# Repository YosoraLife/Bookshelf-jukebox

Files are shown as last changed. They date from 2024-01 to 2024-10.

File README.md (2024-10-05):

# Bookshelf jukebox powered by Plexamp

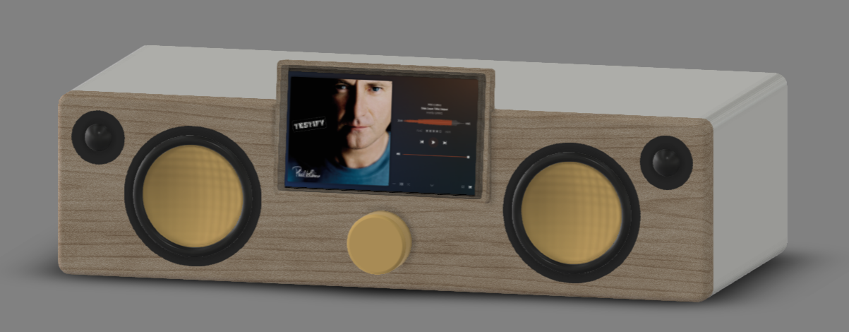
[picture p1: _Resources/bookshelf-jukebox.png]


Read more about this project on: [https://yosora.life/projects/diy-projects/a-bookshelf-jukebox/](https://yosora.life/projects/diy-projects/a-bookshelf-jukebox/)

This jukebox is based on the DIY speakers called "[Overnight Sensations](https://sites.google.com/site/undefinition/bookshelf-speakers/diy-overnightsensations)" by Paul Carmody. Those speakers are powered by a Raspbarry Pi with a high quality DAC and Amplifier. The jukebox itself has both physical controls as well as a touchscreen to interface with Plexamp. Futhermore I included a NFC reader (still a work in progress). This way I can scan a CD case with NFC sticker to play that CD on Plexamp, or setup NFC cards for different playlists based on my mood. 

#### Costs
The total costs for this build came around €475. See the [Bill of Materials](/BOM.md) for a complete specification. 

#### Building plans
The building plans for the jukebox itself can be found [here](/Building%20plans/Plexamp%20jukebox%20buildplan.pdf), and building plans for the speakers crossovers can be found [here](/Building%20plans/Speaker%20cross-over%20buildplan.pdf).

#### Installation instructions
And the installation instructions can be found [here](/INSTALL.md).

#### Specifications speakers
Power handling: 25 watts RMS/50 watts max<br>
Impedance: 8 ohms<br>
Frequency response: 45-20,000 Hz (-3 dB)<br>
Sensitivity: 83 dB 1W/1m

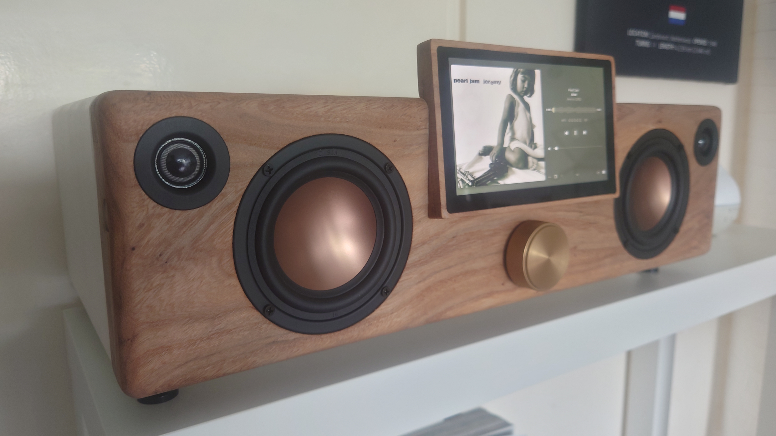
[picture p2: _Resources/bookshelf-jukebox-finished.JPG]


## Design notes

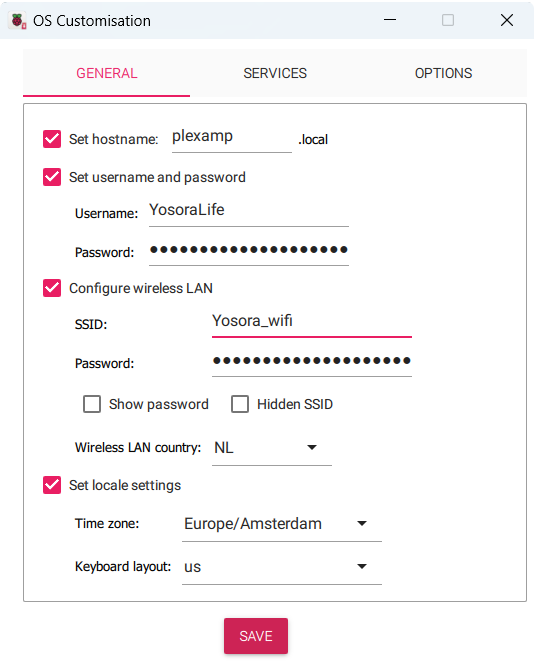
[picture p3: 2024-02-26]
_Resources/RPI_settings.png

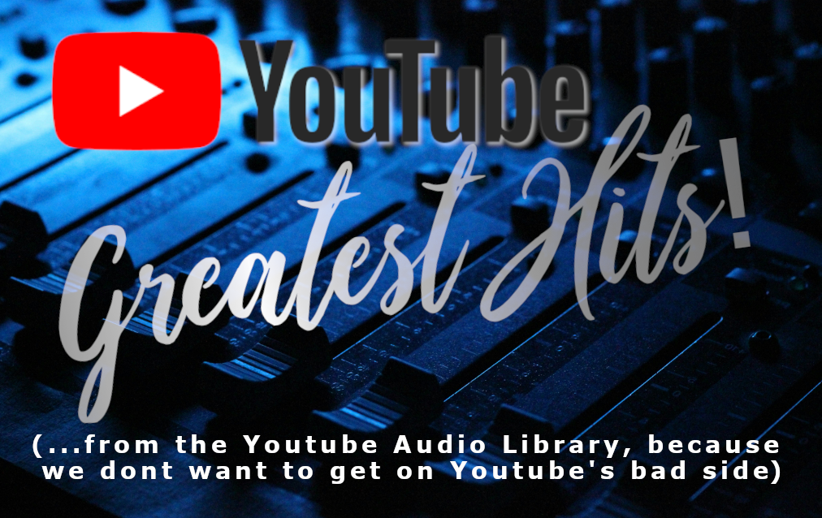
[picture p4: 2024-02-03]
_Resources/Extras/NFC card/Youtube-Greatest-Hits.png

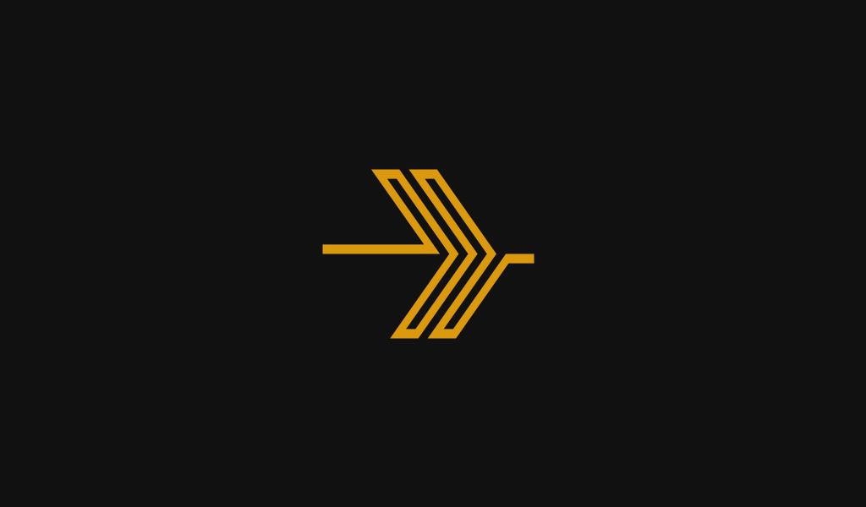
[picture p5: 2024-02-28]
plexamp-splash.png

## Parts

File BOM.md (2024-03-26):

# Bill of materials

### Raspberry Pi
| Amount  | Item  | Total price |
| --- | --- | --- |
| 1 | [Raspberry Pi 3](https://www.raspberrypi.com/products/raspberry-pi-3-model-b-plus/)  | €44,95  |
| 1 | [IQaudIO Pi-DigiAMP+](https://www.raspberrypi.com/products/digiamp-plus/) <br>Also known as Raspberry Pi DigiAMP+  | €34,95  |
| 1 | [Waveshare 7 inch QLED Touch Display](https://aliexpress.com/item/1005004634702269.html) <br>with development board | €77,50 |
| 1 | [NFC PN532 kit](https://aliexpress.com/item/1005005973913526.html) | €4,65 |
| 1 | Power supply 24V @4A *(see notes at the bottom)| €34,95 |
| | **Subtotal** | **€197,00** |

### Speaker components
The speakers are based on the DIY speaker design "[Overnight Sensations](https://sites.google.com/site/undefinition/bookshelf-speakers/diy-overnightsensations)" 
| Amount  | Item  | Total price |
| --- | --- | --- |
| 2	| [Dayton Audio DNR-10 10 Ohm 10W](https://www.soundimports.eu/en/dayton-audio-dnr-10.html) | €2,98 |
| 2	| [Dayton Audio DNR-6.0 6 Ohm 10W](https://www.soundimports.eu/en/dayton-audio-dnr-10.html) | €2,98 |
| 2	| [Dayton Audio DMPC-0.22 0.22uF 250V](https://www.soundimports.eu/en/dayton-audio-dmpc-022.html) | €2,50 |
| 2	| [Dayton Audio DMPC-1.5 1.5uF 250V](https://www.soundimports.eu/en/dayton-audio-dmpc-1-5.html) | €2,90 |
| 2	| [Dayton Audio DMPC-2.2 2.2uF 250V](https://www.soundimports.eu/en/dayton-audio-dmpc-22.html) | €3,70 |
| 2	| [Dayton Audio DMPC-6.8 6.8uF 250V](https://www.soundimports.eu/en/dayton-audio-dmpc-6-8.html) | €6,50 |
| 2	| [Jantzen 1204 0.35mH 20 AWG](https://www.soundimports.eu/en/jantzen-audio-000-1204.html) | €7,70 |
| 2	| [Jantzen 1078 1.1mH 18 AWG](https://www.soundimports.eu/en/jantzen-audio-000-1078.html) | €18,90 |
| 2	| [Dayton Audio ND20FA-6 Tweeter](https://www.soundimports.eu/en/dayton-audio-nd20fa-6.html) | €29,90 |
| 2	| [HiVi B4N Aluminum Midbass](https://www.soundimports.eu/en/hivi-b4n.html) | €44,90 |
| 2 | [Perforated PCB 95*70mm](https://www.soundimports.eu/nl/320-470.html) <br>Alternative: [Crossover PCB for the Overnight Sensations](https://www.ebay.com/itm/283420027089) | €5,90 <br> $20,00 (€18,70)|
| 1 | [Speaker damping](https://www.soundimports.eu/nl/monacor-mdm-2.html) | €10,45 |
| 1 | 1 meter of 32mm PVC pipe for water drainage | €2,79 |
| 2 | 90 degrees bend  for 32mm PVC pipe | €1,90 |
| | **Subtotal** | **€144** |

### Miscellaneous
| Amount  | Item  | Total price |
| --- | --- | --- |
| 1 | Elm wood plank 20x160x1,8cm | €21,45 |
| 1 | MDF 61c122x1,8cm | €16,49 |
| 2 | 2m loudspeaker cable 1,5mm2 | €6,00 |
| 2 | [TTP223 Touch-Knop Module](https://aliexpress.com/item/1005005981286756.html) <br>minimum order of 10, only 2 needed | €0,94 (10st) |
| 1 | [Rotary Encoder](https://aliexpress.com/item/33039321968.html) | €1,94 |
| 1 | [Rimini knob - matt brass 50mm](https://allegreepjes.nl/rimini-knop-mat-messing-50-mm.html) | €19,21 |
| 1 | [22mm metal toggle switch](https://aliexpress.com/item/1005005918066040.html) | €4,10 |
| 1 | [Speaker stands](https://aliexpress.com/item/4000427279953.html) | €8,59 |
| 1 | [Self-adhesive speakerwire foam](https://aliexpress.com/item/1005006204882391.html) | €2,23 |
| 1 | [2x20pin Dupont connectors + terminals](https://aliexpress.com/item/32951306845.html) | €4,30 |
| 1 | [PCB terminal](https://aliexpress.com/item/1005003373535370.html) <br>minimum order of 10, only 1 needed | €1,45 |
| 1 | [Braided heat shrink cable sleeve](https://aliexpress.com/item/1005006219473493.html) <br>diameter 6mm, length 3m | €2,95 |
| 1 | [5.5x2.5mm panel mounted DC connector](https://aliexpress.com/item/4000694128319.html) | €0,75 |
| 1 | [CAT6 ethernet panel mounted connector](https://aliexpress.com/item/1005005363341111.html) | €2,73 |
| 1 | [Rubio Monocoat Oil Plus 2C Pure 100+30ml](https://www.rubiomonocoat.nl/oil-plus-2c) | €30,45 |
| 1 | Matt white paint | €8,95 |
| | **Subtotal** | **€132,53** |

### Plexamp jukebox
**Total cost: €473,53**

Notes:

*To be clear, use all this information at your own risk. I'm not an expert at in this matter at all, and I also rely on information I found online (see resources). So I highly recommend you do your own research in this matter.*

*The digiamp+ can take any power supply ranging from 12-24V DC, with the recommended power supply being 19V, 3.4A (65 watt) DC. That being said, the input voltage does effect the output power per channel. Since the speakers are rated at 25 watts RMS and an impedance of 8 ohms. A recommended amplifier would need 37,5 watts per channel output. At 19V, 8 ohms the IQaudio DigiAmp+ povides an output of 21.3 watts. While at 24V, 8 ohms the IQaudio DigiAmp+ povides an output of 36 watts. And since there is a higher output it also requers a higher input, so a 24V, 4A (96 watt) DC power supply.

But even with a supply voltage of 24V the IQaudio DigiAmp+ is slightly underpowered. So if you would want to use the speakers at maximum volume this could cause problems. But (at least for me) the point of a jukebox is to provide some background music and its not meant to be used at the maximum volume. So then what would the maximum volume be? Well the speakers have a sensitivity of 83 dB 1W/1m. Wich means that at a listing distince of 1 meter a single speaker has a maximum output level of 96,3dB@21,3 watts and 98,6dB@36 watts. Or at a more reasonable lisiting distance of 4 meters this becomes 84,3dB@21,3 watts or 86,6dB@36 watts.

| Power supply voltage | Output power, 8 ohms | 1m listing distance  | 4m listing distance |
| --- | --- | --- | --- |
| 19V | (2x) 21,3 watts | 96,3dB | 84,3dB |
| 24V | (2x) 36 watts | 98,6dB | 86,6dB |

For reference, sounds above 85dB are considered harmfull, while normal level to listen to music would be more around 70dB.

Resources:<br>
[Choosing the right amplifier for your speakers](https://www.gear4music.com/blog/choosing-the-right-amplifier-for-your-speakers/)<br>
[TAS5756M Class-D Amplifier](https://www.ti.com/lit/ds/symlink/tas5756m.pdf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)<br>
[Understanding speaker sensitivity](https://geoffthegreygeek.com/understanding-speaker-sensitivity/)

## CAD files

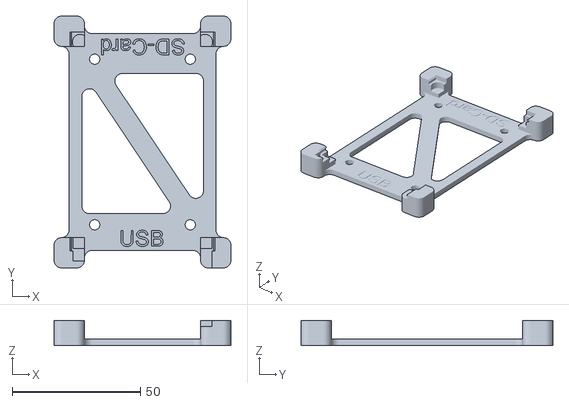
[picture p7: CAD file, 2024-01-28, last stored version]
3D print files/raspberrypi-plate.stl
69.0 x 98.2 x 9.75

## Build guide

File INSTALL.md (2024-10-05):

# Installation instructions bookshelf jukebox

[TOC]

## Prerequisites
### Plex
This installation asummes that you have an active Plex server. [Plex](https://www.plex.tv) is software to manage your personal media collection (Movies, TV series and Music). Plex consist of 2 parts, a central server (Plex Media Server) to manage and stream the media. And the client to play the media. This installation uses Plex dedicated music player called Plexamp for the playback of music. To be able to use the headless version of Plexamp you do need an paid PlexPass subscription.

### NFC reader
The NFC reader was a bit tricky to setup, this code is tested, and meant to be used with:

- A S50 Mifare Classic 1K NFC compatible [card](https://aliexpress.com/item/1005006282512971.html), [sticker](https://aliexpress.com/item/1005005823042872.html) or [FOB](https://aliexpress.com/item/1005006029241048.html) :
- a [Elechouse PN532 V3 NFC/RFID card reader](https://aliexpress.com/item/1005005973913526.html)

### Jukebox
Take a look at the [Bill of Materials](/BOM.md) for a complete list of materials. Building plans for the jukebox itself can be found [here](/Building%20plans/Plexamp%20jukebox%20buildplan.pdf), and building plans for the speakers crossovers can be found [here](/Building%20plans/Speaker%20cross-over%20buildplan.pdf).

## Wiring
The IQaudio DigiAMP+ is connected directly to the Raspberry Pi GPIO header. The power is provided to the IQaudio DigiAMP+ (12-24V DC) that in its turn also provides power to the Raspberry Pi itself. The IQaudio DigiAMP+ also provide GPIO passthrough.

The NFC reader, rotary encoder and 2 touch buttons need to be wired according to following GPIO pins:

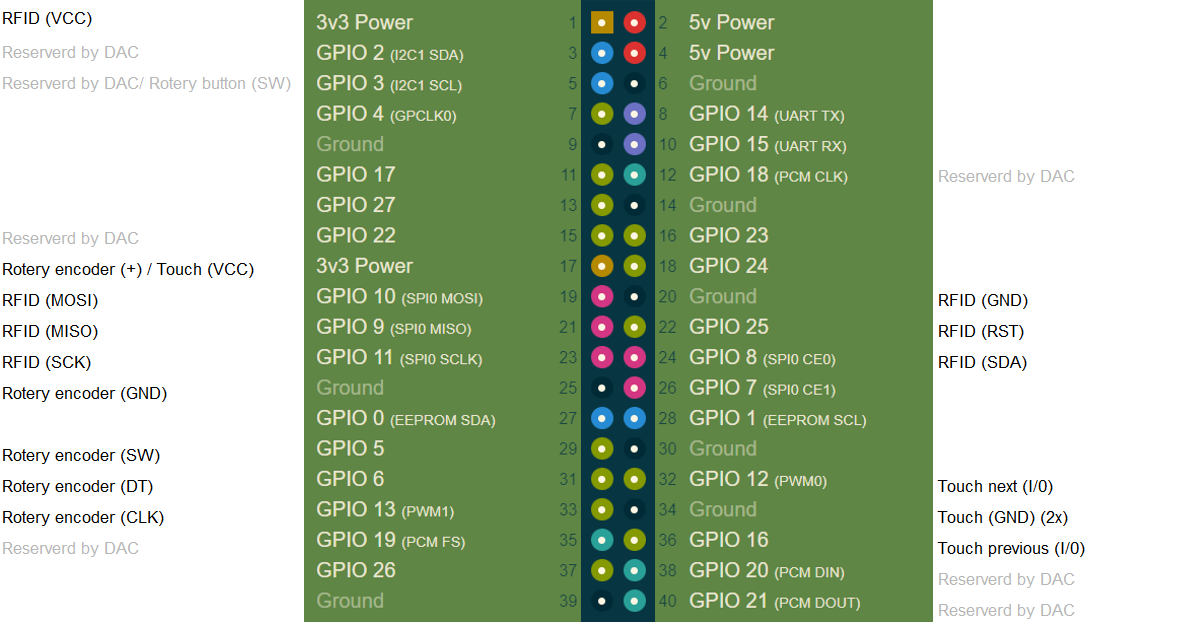
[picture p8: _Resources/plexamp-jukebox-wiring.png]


For reference pin 1 is on the SD card side and pin 40 is on the USB side.

Note: The rotery button (sw) is connected BOTH to pin 5 and pin 29. When the Raspberry Pi is powered off it can be turned on by connecting pin 5 to ground. But when the Raspberry Pi is powered on pin 5 is exclusively used by the DAC and can therefore pin 29 is used instead.

## Installation of the hardware
Download the [DietPi Bookworm](https://dietpi.com/#downloadinfo) image for Raspberry Pi 2/3/4/Zero 2 (ARMv8). unzip it with a tool like [7Zip](https://www.7-zip.org). I always prefer to use [rufus](https://rufus.ie/) to flash the dietpi.img to a SD card. Wait for the flashing process to be finished.

Dietpi has some great way to automate the setup process. Follow the follow steps in order to make use of that:

### Setup wifi
The following steps are only needed if you want to make use of WiFi, open the SD card folder, and update next two files using a text editor:

In the file dietpi-wifi.txt:

- set `aWIFI_SSID[0]` to the name of your WiFi network (keep the qoutes)
- set `aWIFI_KEY[0]` to the password of your WiFi network (keep the qoutes)

Save and close the file

**Enable wifi:**
In the file named dietpi.txt:

- find `AUTO_SETUP_NET_WIFI_ENABLED` and set to value `1`
- find `AUTO_SETUP_NET_WIFI_COUNTRY_CODE` and set it too the correct countrycode

### Setup locale
(Still) In the file dietpi.txt:

- find `AUTO_SETUP_LOCALE=c.UTF-8`, change the c.UTF-8 for your own localization. In my case this would be `nl_NL.UTF-8` or for English: `en_GB.UTF-8`. Im not sure if this is 100% necessary but the first time running without this caused the keyboard setup to fail.
- find `AUTO_SETUP_KEYBOARD_LAYOUT`, set the keyboard layout. You only need the keyboard to login to the Plexamp userinterface
- find `AUTO_SETUP_TIMEZONE` and set your correct timezone

### Setup dietpi:
(Still) In the file dietpi.txt:

- find `AUTO_SETUP_NET_HOSTNAME` and set it to: `Jukebox`
- find `AUTO_SETUP_CUSTOM_SCRIPT_EXEC` and set it to: `https://gitlab.com/YosoraLife/bookshelf-jukebox/-/raw/main/jukebox-install.sh` (no qoutes needed)
- find `AUTO_SETUP_BROWSER_INDEX` and set it to `-2`
- find `AUTO_SETUP_AUTOSTART_TARGET_INDEX` and set it to `11`
- find `AUTO_SETUP_AUTOSTART_LOGIN_USER` and set it to `root`
- find `AUTO_SETUP_AUTOMATED` and set it to `1`
- find `AUTO_SETUP_INSTALL_SOFTWARE_ID` and add to the line underneath:

```bash
AUTO_SETUP_INSTALL_SOFTWARE_ID=5 # Install ALSA
AUTO_SETUP_INSTALL_SOFTWARE_ID=17 # Install Git
AUTO_SETUP_INSTALL_SOFTWARE_ID=69 # Install RPi.GPIO
AUTO_SETUP_INSTALL_SOFTWARE_ID=72 # Install I2C
AUTO_SETUP_INSTALL_SOFTWARE_ID=113 # Install Chromium
AUTO_SETUP_INSTALL_SOFTWARE_ID=130 # Install Python 3 pip
```

- find `SURVEY_OPTED_IN` and set it to what your comfortable with
- find `SOFTWARE_CHROMIUM_RES_X` and set it to your screens width, in my case `1024`
- find `SOFTWARE_CHROMIUM_RES_Y` and set it to your screens height, in my case `600`
- find `SOFTWARE_CHROMIUM_AUTOSTART_URL` and set it to: `http://127.0.0.1:32500/`

### Recommandations:

- find `AUTO_SETUP_GLOBAL_PASSWORD` and change the root password

Save and close the file

### Setup screen
In the file named config.txt add to the bottom:

```bash
hdmi_group=2
hdmi_mode=87
hdmi_cvt 1024 600 60 6 0 0 0
hdmi_drive=1
# Disable HDMI audio
dtoverlay=vc4-kms-v3d,noaudio
# Enable DAC
dtoverlay=iqaudio-dacplus,unmute_amp
```

Save and close the file. And now its time to put the sd card in the Raspberry Pi and boot up for the first time. The installation of all the required software starts automaticly. The Raspberry Pi does need an active internet connection. So make sure you either have set up a wired or a wireless connection.

Dietpi automatically run through all installation steps. Near the end you will be prompted to enter your Plex claim code followed by the prompt to name your Plexamp player. Make sure you have a keyboard connected to the Raspberry Pi for this. When finished the Raspberry Pi will reboot into the Plexamp interface. Even though you claimed the Plexamp player already you will still need to do a (onetime) login into the (web)interface with your Plex credentials. For this you also need to have a keyboard connected to your Raspberry Pi. After this you don't need an keyboard anymore since you can use SSH to access the jukebox.

## SSH into the jukebox
You can use SSH to access the jukebox from another computer. Use a tool like [Advanced IP scanner](https://www.advanced-ip-scanner.com/) to find the IP address of the Jukebox. Next use [PuTTY](https://www.putty.org) to connect to the jukebox. The username is root, and the default password is "dietpi", although you should have changed that in the previous step.

### Enable autoplay on boot
By default Plexamp doesnt start playing until music is choosen. You can enable the script to autoplay the (general) Library radio.

In a webbrowser go to the following page on you **Plex Media Server** and find the *machineIdentifier*

```bash
http://[IP  address]:32400/identity/
```

Edit the Plexamp controls:

```bash
cd  ~/bookshelf-jukebox
sudo nano settings.py
```
Find `PLEX_ID` and set the machineIdentifier.

Here you can also change the short and long press duration, the volume adjustment steps, starting volume at boot and screen timeout at idle (no playing).

### Changing sound levels

Now these speakers can go LOUD! If you ask me, way too loud. I like to use this bookshelf speakers more as background music, and only occasionally turning op the volume. But even when I do turn up the volume I could never push them above 50% volume on Plexamp, while only being more around 5% volume at background music levels.

This would make the volume knob pretty useless of course. Luckily there is a way to manage this. You can adjust the maximum volume levels for the soundcard. By changing the maximum levels for the soundcard you can use the entire volume range on Plexamp.

Open AlsaMixer:
```bash
alsamixer
```

Choose the sound card by hitting `F6` and selecting IQaudIODAC. You will now see different sound levels meters. Use the left and right arrow keys to select the "Digital" sound level meter, and use the up and down arrow keys to change the sound levels. This can be done while playing music. I set mine to 67%.

When the desired level is set hit the ESC key to exit alsamixer.

## Controlling the Jukebox

### Turning off/on
If you build your jukebox just like mine you will have a power toggle at the back, and at the front a volume control knob and a previous/next touch button. DO NOT use the power toggle to shutdown the Raspberry Pi, this can cause a corrupt SD card! 

The correct way of shutting down is to long press the volume knob until the system is in idle state. Only then it's safe to turn off the power toggle. When the power toggle is turned on it will automatically boot the system. Alternatively if the system is still in idle state it can be turned back on by pressing the volume knob.

### Physical controls
You can use the touchscreen, volume knob and previous/next touch buttons. The volume knob also doubles as play/pause (short press) or off/on (long press).

### Control by phone
You can control the jukebox with the Plexamp app for both iPhone and Android. Use the cast function in the app and select the jukebox. Your phone will now work as a remote for the jukebox.

### Control by web browser
Similarly you can control the jukebox by going to `http://[IP  address]:32500/`

## Updating plexamp
Check the [plexamp download](https://www.plex.tv/media-server-downloads/?cat=headless&plat=raspberry-pi#plex-plexamp) page to see the required NodeJS (Node) version

Check if the right version is installed:

```bash
node  -v
```

If needed update NodeJS

```bash
NODE_MAJOR=20
echo  deb [signed-by=/etc/apt/keyrings/nodesource.gpg] https://deb.nodesource.com/node_$NODE_MAJOR.x nodistro main | sudo  tee  /etc/apt/sources.list.d/nodesource.list
sudo  apt-get  update && sudo  apt-get  install  -y  nodejs
```

replace `20` with the required NodeJS version

Check for update (one time):

```bash
sh  /root/bookshelf-jukebox/plexamp-upgrade.sh
```

You can setup an automatic weekly update run: 

```bash
sudo (crontab -l; echo  "@weekly /usr/bin/sh /root/bookshelf-jukebox/plexamp-upgrade.sh &")|awk  '!x[$0]++'|crontab  -
```

 Be aware: this will only run the plexamp update script and it will not update NodeJS. 
At times a newer version of Plexamp also requires a newer version of NodeJS (Node). The required version of NodeJS (node) can be found on the download page: https://www.plex.tv/media-server-downloads/?cat=headless&plat=raspberry-pi#plex-plexamp

To check the installed version of NodeJS connect to the Raspberry Pi through SSH an run the command: node -v

If needed update NodeJS

```bash
NODE_MAJOR=20
echo  deb [signed-by=/etc/apt/keyrings/nodesource.gpg] https://deb.nodesource.com/node_$NODE_MAJOR.x nodistro main | sudo  tee  /etc/apt/sources.list.d/nodesource.list
sudo  apt-get  update && sudo  apt-get  install  -y  nodejs
```

replace `20` with the required NodeJS version

And finally reboot:
```bash
sudo reboot now
```

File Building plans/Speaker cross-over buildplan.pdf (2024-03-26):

Full credits to user “Soundslike” on the parts-express.com forum for making crossover build plan. For the original post: https://techtalk.parts-express.com/forum/speaker-project-gallery/42859-overnight-sensation-build-two-sets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 (https://techtalk.parts-express.com/forum/speaker-project-gallery/42859-overnight-sensation-build-two-sets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)

## Materials needed

For the Materials needed look at the Bill of materials > Speaker components (https://gitlab.com/YosoraLife/bookshelf-jukebox/-/blob/main/BOM.md?ref_type=heads#speaker-components)

## Wiring diagram

This wiring diagram is in mirrored view. So as if you where looking through the board from the bottom side. The red and blue lines are connection lines and the dots is where the connection lines meet. If 2 connection lines cross without a dot there shouldn’t be an electrical connection made.

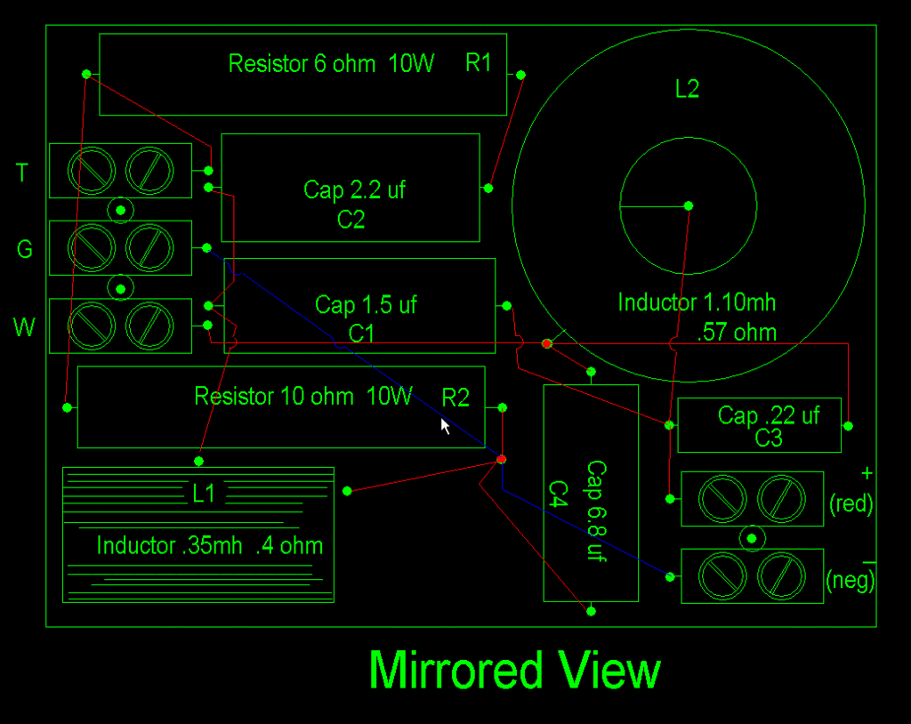
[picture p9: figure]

## Results

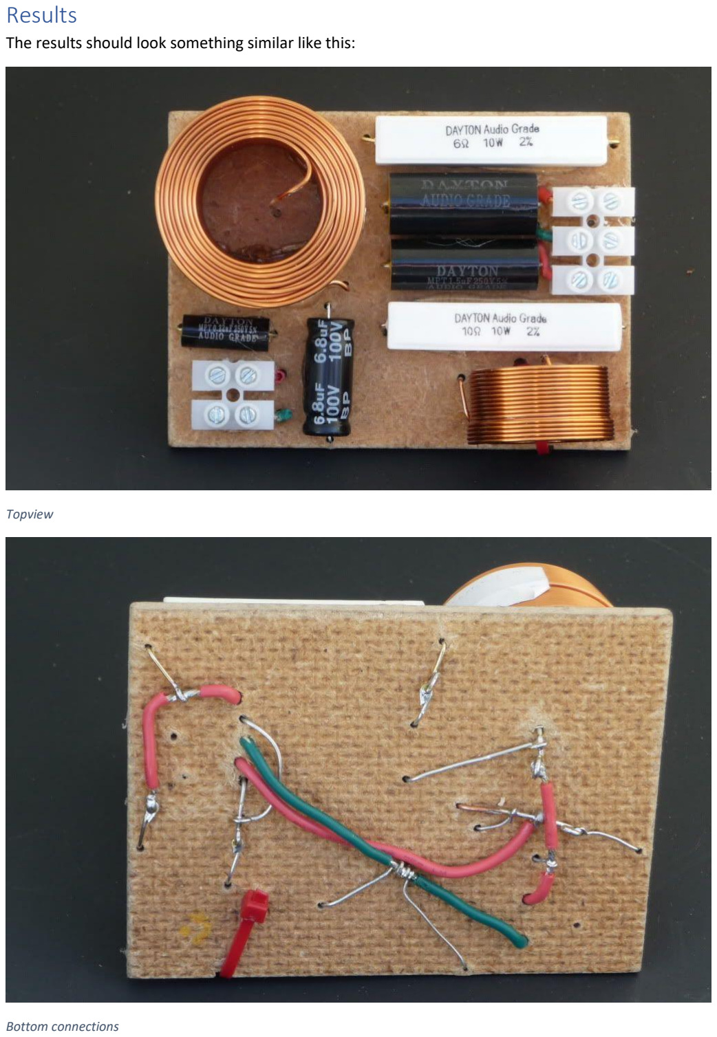
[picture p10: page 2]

The results should look something similar like this:

Topview

Bottom connections

## Connecting the speakers

On the input side the terminal on the outside of the board is the negative (-) terminal, while the other one is the positive (+) terminal as indicated on the picture below.

On the output side the middle terminal is the ground (G) terminal. To this terminal you need the negative (-) side of the woofer and the positive (+) side of the tweeter.
The positive tweeter (T) terminal need to connect to the negative (-) side of the tweeter.
And the positive woofer (W) terminal needs to connect to the positive (+) side of the woofer.

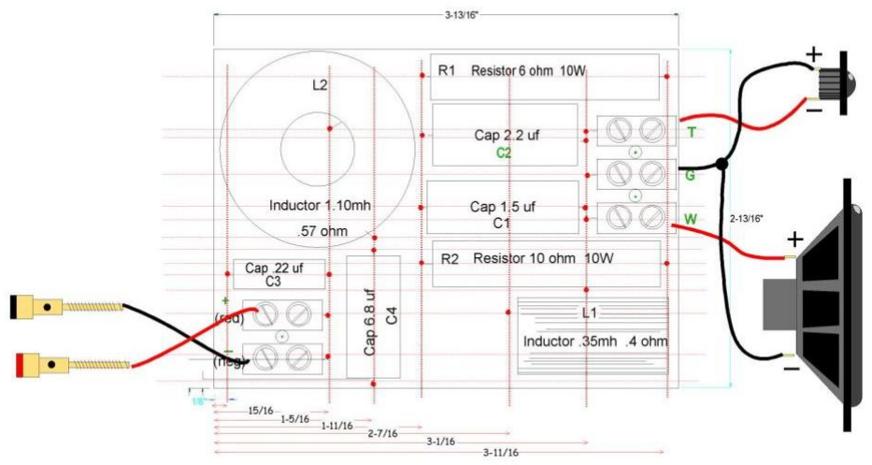
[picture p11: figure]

Tip: Test if everything works before you mount it in the speaker cabinate.

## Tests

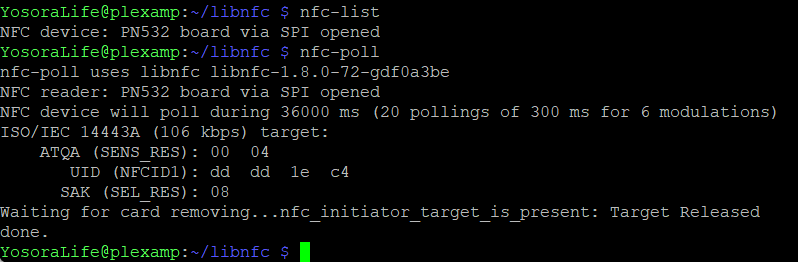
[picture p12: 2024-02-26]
_Resources/nfc-test.png

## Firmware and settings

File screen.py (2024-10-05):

#! /usr/bin/env python3
# Bookshelf jukebox screen control

import time
import settings
from functions import getState, setScreen

##########################################################################################################
####### DONT CHANGE THE SETTINGS INBETWEEN THESE LINES. INSTEAD CHANGE THE SETTINGS IN SETTINGS.PY #######

# Screen backlight control
SCREEN_TIMEOUT = settings.SCREEN_TIMEOUT                            # Turn screen backlight off after * minutes

####### DONT CHANGE THE SETTINGS INBETWEEN THESE LINES. INSTEAD CHANGE THE SETTINGS IN SETTINGS.PY #######
##########################################################################################################

###################################################
### Initial state setup ###########################
###################################################
SCREEN_TIMEOUT_START = time.time()                                  # Start tracking of the time
PB_PREV_STATE = 'paused'                                            # Assume the initial state of the player is paused
setScreen('on')                                                     # Start with the screen on

###################################################
### Paused state handeling ########################
###################################################
def handle_paused_state():
    global SCREEN_TIMEOUT_START
    screen_timeout_duration = time.time() - SCREEN_TIMEOUT_START    # Calculate the time duration since last pause
    if screen_timeout_duration > (SCREEN_TIMEOUT * 60):             # Check if timeout time is already exceeded
        setScreen('off')                                            # Turn off screen

###################################################
### Playing state handeling #######################
###################################################
def handle_playing_state():
    setScreen('on')                                                 # Turn on screen, playback has started

while True:
    current_state = getState('state')                               # Get the current state

    if current_state == 'playing':                                  # State is playing
        if PB_PREV_STATE != 'playing':                              # Previous state was not playing
            PB_PREV_STATE = 'playing'                               # Set new previous state variable
            handle_playing_state()                                  # Turn on screen, playback has started

    else:                                                           # If state is paused or stopped
        if PB_PREV_STATE == 'playing':                              # Previous state was playing
            PB_PREV_STATE = 'paused'                                # Set new previous state variable
            SCREEN_TIMEOUT_START = time.time()                      # Reset tracking of the time
        handle_paused_state()                                       # Check if the screen should turn off after timeout

    time.sleep(5)                                                   # Run loop once every 5 seconds to reduce CPU usage

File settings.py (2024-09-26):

#! /usr/bin/env python3
# Bookshelf jukebox setings

# Times for button presses
SHORT_PRESS_TIME = 1.5                      # Time for shortpress in seconds
LONG_PRESS_TIME = 2.0                       # Time for longpress in seconds
DEBOUNCE_TIME = 100                          # Debounce time in mili seconds, default = 100. Increase when experience unwanted "extra" button presses 

# Volume steps
VOLUME_ADJUSTEMENT = 3                      # How much to add to the volume every step. Range: 0-100

# At boot there is no playlist yet. For autoplay library radio to work you need the machineIdentifier of your plexserver
PLEX_ID = ''                                # Find the machineIdentifier at http://[IP address]:32400/identity/
AUTOPLAY = 0                                # 0 = Autoplay on start (dont forget to fill in your PLEX_ID), 1 = No autoplay on start
START_VOLUME = 10                           # Set volume level at start Range: 1-100, 0 = disable

# Screen backlight control
SCREEN_TIMEOUT = 5                          # Turn screen backlight off after * minutes

# Pin numbers on Raspberry Pi
CLK_PIN = 13                                # GPIO7 connected to the rotary encoder's CLK pin
DT_PIN = 6                                  # GPIO8 connected to the rotary encoder's DT pin
SW_PIN = 5                                  # GPIO5 connected to the rotary encoder's SW pin
NEXT_PIN = 12                               # GPIO12 connected to the next song touch button pin
PREV_PIN = 16                               # GPIO16 connected to the previous song touch button pin
SCREEN_PIN = 23                             # GPIO23 connected to the screen backlight pin

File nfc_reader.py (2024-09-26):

#! /usr/bin/env python3

"""
    NFC Reader for Mifare Classic 1K cards using Elechouse PN532 V3 NFC/RFID card reader.
    Reads and converts the contents of the NFC card back to a URL and opens it.
"""

import curlify
import requests
import time

from pn532pi import pn532, Pn532
from pn532pi import Pn532Hsu
from pn532pi import Pn532Spi

SPI = True
HSU = False

# Configure NFC reader connection mode (SPI or HSU)
if SPI:
    PN532_SPI = Pn532Spi(Pn532Spi.SS0_GPIO8)
    nfc = Pn532(PN532_SPI)
elif HSU:
    PN532_HSU = Pn532Hsu(Pn532Hsu.RPI_MINI_UART)
    nfc = Pn532(PN532_HSU)


def setup():
    """Setup NFC module and wait until it is found."""
    module_found = False
    retries = 10  # Max retries to avoid indefinite looping
    while not module_found and retries > 0:
        nfc.begin()
        version_data = nfc.getFirmwareVersion()
        if version_data:
            module_found = True
        else:
            retries -= 1
            time.sleep(1)
    if module_found:
        nfc.SAMConfig()
    else:
        print("Error: NFC module not found. Exiting.")
        exit(1)


if __name__ == '__main__':
    setup()

    key_universal = bytearray([0xFF, 0xFF, 0xFF, 0xFF, 0xFF, 0xFF])

    while True:
        authenticated = False
        data_strings = ['http://']  # Collect strings in a list for better efficiency

        success, uid = nfc.readPassiveTargetID(pn532.PN532_MIFARE_ISO14443A_106KBPS)
        if success and len(uid) == 4:
            block_count = 0
            empty_block_count = 0

            # Try to read all 16 sectors (each sector has 4 blocks)
            for current_block in range(64):
                if block_count == 3:
                    block_count = 0  # Skip every 4th block (authentication block)
                    continue
                block_count += 1

                if nfc.mifareclassic_IsFirstBlock(current_block):
                    authenticated = False

                # Authenticate if needed
                retry_limit = 3
                while not authenticated and current_block > 3 and retry_limit > 0:
                    success = nfc.mifareclassic_AuthenticateBlock(uid, current_block, 1, key_universal)
                    if success:
                        authenticated = True
                    else:
                        retry_limit -= 1

                if authenticated:
                    empty_block = bytearray([0x00] * 16)
                    success, data = nfc.mifareclassic_ReadDataBlock(current_block)

                    if data == empty_block:
                        empty_block_count += 1
                        if empty_block_count > 3:
                            break  # Stop if more than 3 consecutive empty blocks are found
                    elif success:
                        empty_block_count = 0
                        if current_block == 4:
                            data = data[7:]  # Skip first 7 bytes (start of data)
                        data_strings.append(data.decode('utf8', 'ignore'))

        if data_strings:
            url = ''.join(data_strings).replace("listen.plex.tv", "localhost:32500")
            try:
                response = requests.get(url)
                print(curlify.to_curl(response.request))
            except requests.RequestException as e:
                print(f"Error opening URL: {e}")

        time.sleep(3)  # Sleep before the next read attempt

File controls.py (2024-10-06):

#! /usr/bin/env python3
# Bookshelf jukebox controls

import RPi.GPIO as GPIO
import time
import os
import settings
from functions import *

##########################################################################################################
####### DONT CHANGE THE SETTINGS INBETWEEN THESE LINES. INSTEAD CHANGE THE SETTINGS IN SETTINGS.PY #######

# Pin numbers on Raspberry Pi
CLK_PIN = settings.CLK_PIN                          # GPIO7 connected to the rotary encoder's CLK pin
DT_PIN = settings.DT_PIN                            # GPIO8 connected to the rotary encoder's DT pin
SW_PIN = settings.SW_PIN                            # GPIO5 connected to the rotary encoder's SW pin
NEXT_PIN = settings.NEXT_PIN                        # GPIO12 connected to the next song touch button pin
PREV_PIN = settings.PREV_PIN                        # GPIO16 connected to the previous song touch button pin

# Times for button presses
SHORT_PRESS_TIME = settings.SHORT_PRESS_TIME        # Time for shortpress in seconds
LONG_PRESS_TIME = settings.LONG_PRESS_TIME          # Time for longpress in seconds
DEBOUNCE_TIME = settings.DEBOUNCE_TIME              # Debounce time in milli seconds, default = 100. Increase when experience unwanted "extra" button presses 

# Volume steps
VOLUME_ADJUSTEMENT = settings.VOLUME_ADJUSTEMENT    # How much to add to the volume every step. Range: 0-100

# At boot there is no playlist yet. For autoplay library radio to work you need the machineIdentifier of your plexserver
PLEX_ID = settings.PLEX_ID                          # Find the machineIdentifier at http://[IP address]:32400/identity/
AUTOPLAY = settings.AUTOPLAY                        # 0 = Autoplay on start, 1 = No autoplay on start
START_VOLUME = settings.START_VOLUME                # Set volume level at start Range: 1-100, 0 = disable

####### DONT CHANGE THE SETTINGS INBETWEEN THESE LINES. INSTEAD CHANGE THE SETTINGS IN SETTINGS.PY #######
##########################################################################################################

# General variables
PRESS_TIME_START = 0
IS_PRESSED = False

# Configure GPIO pins
GPIO.setmode(GPIO.BCM)
GPIO.setup(CLK_PIN, GPIO.IN)
GPIO.setup(DT_PIN, GPIO.IN)
GPIO.setup(SW_PIN, GPIO.IN, pull_up_down=GPIO.PUD_UP)
GPIO.setup(NEXT_PIN, GPIO.IN, pull_up_down=GPIO.PUD_UP)
GPIO.setup(PREV_PIN, GPIO.IN, pull_up_down=GPIO.PUD_UP)

prev_clk_state = GPIO.input(CLK_PIN)                        # Read the initial state of the rotary encoder's CLK pin

###################################################
### Autoplay functionality ########################
###################################################
def autoplay():
    if AUTOPLAY == 0 and PLEX_ID != '':                     # Check if autoplay is enabled and a PLEX ID is present
        if START_VOLUME >= 1 and START_VOLUME <= 100:       # Check if there is a start volume set
            setState(START_VOLUME)                          # Set start volume
        setState('playMedia')                               # Start playback

###################################################
### Rotery encoder functionality ##################
###################################################
def rotary_encoder_callback(channel):
    #global prev_clk_state
    #if GPIO.input(CLK_PIN) != prev_clk_state:               # Detect state change of CLK pin
    # Check state of the DT pin
    if GPIO.input(DT_PIN) == GPIO.HIGH:                 # State DT pin is high? Then its turning counter-clockwise
        setState('volDown')                             # Turn volume down
    elif GPIO.input(DT_PIN) == GPIO.LOW:                # Else the state of DT pin is low. Then its turning clockwise
        setState('volUp')                               # Turn volume up
    prev_clk_state = GPIO.input(CLK_PIN)                # Set state for the next turn

###################################################
### Rotery button functionality ###################
###################################################
def rotary_button_callback(channel):
    global PRESS_TIME_START, IS_PRESSED
    if GPIO.input(SW_PIN) == GPIO.LOW:                      # Detect button being pressed
        PRESS_TIME_START = time.time()                      # Start tracking the time
        IS_PRESSED = True                                   # Set variable for long press detection
    elif GPIO.input(SW_PIN) == GPIO.HIGH:                   # Detect button being released
        IS_PRESSED = False                                  # Reset variable for long press detection
    
        # Handle short button press, Long button press (Poweroff) is handled by check_long_press()
        press_duration = time.time() - PRESS_TIME_START      # Calculate press duration
        if press_duration < SHORT_PRESS_TIME:                # Check for short press
            if getState('state') == 'stopped':               # Check if current state is stopped
                setState('playMedia')                        # Start playback
            else:
                setState('playPause')                        # Pause playback

###################################################
### Rotery button long press check ################
###################################################
def check_long_press():
    global PRESS_TIME_START
    if GPIO.input(SW_PIN) == GPIO.LOW:                      # Check if button is still being pressed
        press_duration = time.time() - PRESS_TIME_START     # Calculate the time duration of it being pressed
        if press_duration > LONG_PRESS_TIME:                # If button is being pressed long time shutdown system
            setState('stop')                                # Stop playing
            os.system('sudo shutdown -h now')               # Shutdown system
    else:
        PRESS_TIME_START = 0                                # Reset time tracking
        IS_PRESSED = False                                  # Button is not pressed anymore, reset state

###############################################
### Touch next button functionality ###########
###############################################
def next_button_callback(channel):
    setState('next')                                        # Play next song

###################################################
### Touch previous button functionality ###########
###################################################
def prev_button_callback(channel):
    setState('prev')                                        # Play previous song
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

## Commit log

2024-01-31 Added crossover buildplan
    [raspberrypi-plate.stl]
2024-02-06 Add images
    [raspberrypi-plate.stl]
2024-02-13 Added BOM
2024-02-13 Updated BOM
2024-02-14 Update BOM
2024-02-26 Added wiring
2024-09-26 Code rewrite for interuption based buttons
